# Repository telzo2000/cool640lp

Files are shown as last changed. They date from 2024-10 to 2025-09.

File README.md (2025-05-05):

# cool640lp

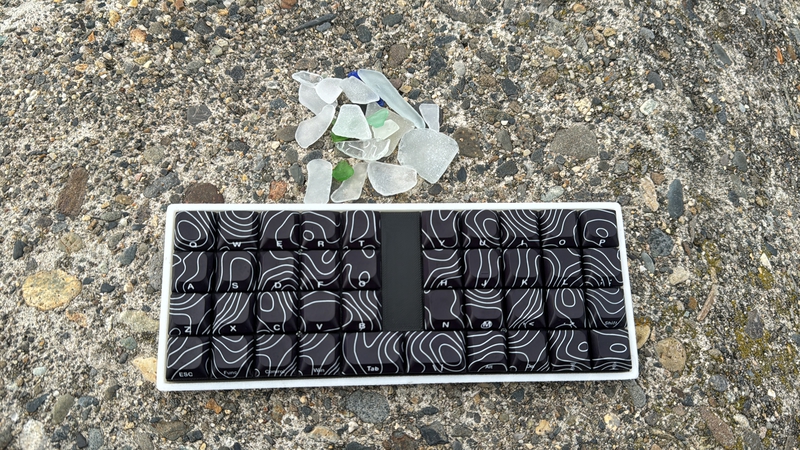
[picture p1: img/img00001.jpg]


## What is cool640lp?

cool640lp is ortholiner keyboard.
<br>
This keyboard has 40 keys.
<br>
This keyboard use Ble Micro Pro,run qmk_firmware.
<br>

## firmware

https://github.com/telzo2000/cool640lp/tree/main/firmware

## build guide

https://github.com/telzo2000/cool640lp/blob/main/buildguide_for_cool640lp.md

<br>

## build log

2024/11/21　build and writen by @MeriNakamura
<br>
https://note.com/merinakamura/n/n6db176bb61fc
<br>
2024/11/26 build and writen by @kazy_developer
<br>
https://note.com/kazy_developer/n/nb938d122a83f?sub_rt=share_sb
<br>
2024/12/26 buile and written by @catfist
<br>
https://note.com/catfist/n/n36a9d9e28e62?sub_rt=share_pb
<br>

### summary

1 Diode soldering
<br>
2 Switch socket soldering
<br>
3  Battery Patrs,etc soldering
<br>
4 Ble Micro Pro and conthrough soldering
<br>
5 Install firmware
<br>
6 Fix the switch plate with screws
<br>
7 Insert the key switch
<br>
8 Fix the bottom case with screws.
<br>
9 Complete
<br>

## Parts list

| No. | Patrs | Quantity | remarks | Suppliers | Cost |
|--|--|--|--|--|--|
|番号|名前|数|備考|調達先|参考価格（送料込）|<br>
|1|PCB|1|40key|[elecrow](https://www.elecrow.com)<br>[JLCPCB](https://jlcpcb.com)<br>[ALLPCB](https://www.allpcb.com)|５枚で20〜30ドル|<br>
|2|BLE Micro Pro|1|MCU Board|[遊舎工房](https://shop.yushakobo.jp/products/ble-micro-pro?variant=37665571340449)|4950円|
|3|Swith socket<br>スイッチソケット|40|choc V2|[遊舎工房](https://yushakobo.jp)<br>[Talp Keyboard](https://talpkeyboard.net)<br>[Daily Craft Keyboard](https://shop.dailycraft.jp)等|10個で165円程度|
|4|Diode<br>ダイオード|40|SMD|[遊舎工房](https://yushakobo.jp)<br>[Talp Keyboard](https://talpkeyboard.net)<br>[Daily Craft Keyboard](https://shop.dailycraft.jp)等|100個で220円程度から|
|5|Switch plate|1|3D Print|||
|6|Bottom case|1|3D Print||
|7|Screw<br>ネジ|8|M2 4mm|DIY shop|10本200円程度|
|8|Spacer<br>スペーサー|4|M2 3mm|DIY shop|10本400円程度|
|9|Conthrou<br>コンスルー|2|3.5mm|[Talp Keyboard](https://talpkeyboard.net)|１個250円程度|
|11|Keyswitch<br>キースイッチ|40|お好みで|[遊舎工房](https://yushakobo.jp)<br>[Talp Keyboard](https://talpkeyboard.net)<br>[Daily Craft Keyboard](https://shop.dailycraft.jp)|１個100程度|
|12|Keycap<br>キーキャップ|40|1Ux38、1.5Ux2|[遊舎工房](https://yushakobo.jp)<br>[Talp Keyboard](https://talpkeyboard.net)<br>[Daily Craft Keyboard](https://shop.dailycraft.jp)||
|13|ボタン電池ホルダー|1|1632|[アリエク](https://ja.aliexpress.com/item/32744211091.html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)<br>|100個で900円ほど|
|14|水平スライドスイッチ|1||[秋月電子](https://akizukidenshi.com/catalog/g/g115370/)|30円|
|15|チップ積層セラミックコンデンサー |1|100μF6.3V F 3216|[秋月電子](https://akizukidenshi.com/catalog/g/g102151/)|10個入り200円|

※13,14,15は[遊舎工房の「Primer29/61用電池部品セット（コイン電池」](https://shop.yushakobo.jp/products/5623)が最適。

In addition, you will need a USB cable, etc.
<br>
この他に、USBケーブル等が必要です。
<br>

## lisence

[CC BY-NC-SA](https://creativecommons.org/licenses/by-nc-sa/4.0/deed.ja)



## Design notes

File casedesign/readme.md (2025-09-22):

# Case design

## switchplate

With my home FDM 3D printer, intersections of less than 0.1mm occur. Therefore, the 3D data is created with a switch frame of 14 mm on each side. With the outsourced stereolithography 3D printer, there are very few intersections of less than 0.1 mm. Therefore, the 3D data is created with a switch frame of 13.85 mm on each side.
<br>
自宅のFDM方式の３Dプリンタでは、0.1mm以下の交差が発生します。そのため、３Dデータは、スイッチの枠を１辺14mmで作成しています。外注先の光造形の３Dプリンタでは、0.1mm以下の交差はあまりないです。そのため、３Dデータは、スイッチの枠を１辺13.85mmで作成しています。
<br>
<br>
The two switches have different claw widths.
<br>
If you use JLCPCB 3D printing survice,
<br>
You shoose
cool640lp_switchplate_for_jlcpcb_rezin.stl
<br>

If the switch you use is Lofree ghost,
<br>
You choose cool640lp_seitchplate_for_lofreeghost.stl.
<br>
If the switch you use is Deep Sea silent mini,
<br>
You choose cool640lp_switchplate_for_ds.stl.
<br>

## bottomcase

Bottomcase has two desigens.
<br>
You can choose whichever bottom case you like and use it.
<br>

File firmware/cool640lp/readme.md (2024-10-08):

# cool640lp

cool640lp

*A short description of the keyboard/project*

* Keyboard Maintainer: [m.ki](https://github.com/telzo2000)
* Hardware Supported: *The PCBs, controllers supported*
* Hardware Availability: *Links to where you can find this hardware*

Make example for this keyboard (after setting up your build environment):

    make cool640lp:default

Flashing example for this keyboard:

    make cool640lp:default:flash

See the [build environment setup](https://docs.qmk.fm/#/getting_started_build_tools) and the [make instructions](https://docs.qmk.fm/#/getting_started_make_guide) for more information. Brand new to QMK? Start with our [Complete Newbs Guide](https://docs.qmk.fm/#/newbs).

## Bootloader

Enter the bootloader in 3 ways:

* **Bootmagic reset**: Hold down the key at (0,0) in the matrix (usually the top left key or Escape) and plug in the keyboard
* **Physical reset button**: Briefly press the button on the back of the PCB - some may have pads you must short instead
* **Keycode in layout**: Press the key mapped to `QK_BOOT` if it is available

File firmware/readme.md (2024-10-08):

# firmware

## Ble Micro Pro

If you read [here](https://sizu.me/m_ki/posts/01s8uea4u7x8) in japanese,you can install Ble Micro Pro on cool640lp.
<br>
日本語で[ここ](https://sizu.me/m_ki/posts/01s8uea4u7x8)を読むと、cool640lpにBle Micro Proをインストールできます。
<br>
<br>

## Pro micro

Install cool640lp_vial.hex to cool640lp using QMK toolbox.
<br>
QMK toolboxを使って、cool640lp_vial.hexをcool640lpにインストールしてください。
<br>

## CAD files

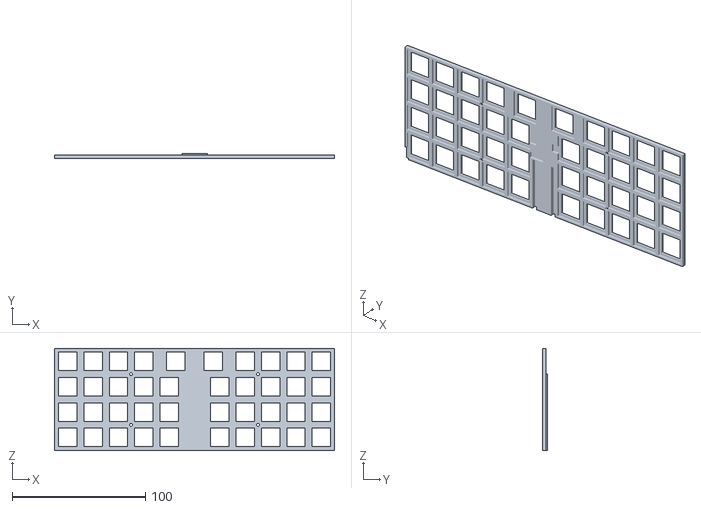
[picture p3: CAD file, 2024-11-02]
casedesign/cool640lp_switchplate_for_jlcpcb_rezin.stl
210.2 x 3.50 x 76.8

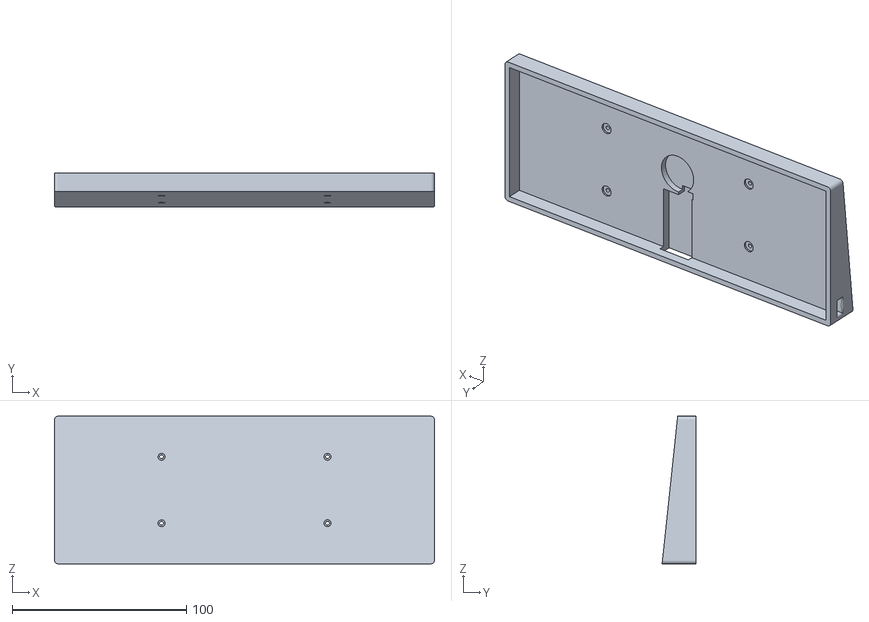
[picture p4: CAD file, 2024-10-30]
casedesign/cool640lp_easybottomcase.stl
218.2 x 19.4 x 84.8

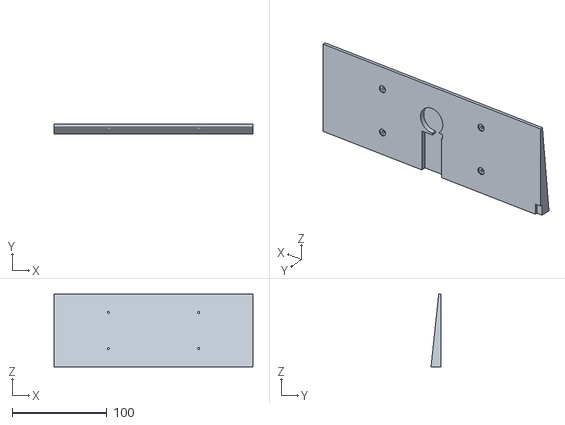
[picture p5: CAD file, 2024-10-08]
casedesign/cool640lp_bottomplate.stl
210.2 x 10.5 x 76.8

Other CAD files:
casedesign/cool640lp_bottomcase.stl
casedesign/cool640lp_switchplate_for_ds v15.stl
casedesign/cool640lp_switchplate_for_lofreeghost.stl

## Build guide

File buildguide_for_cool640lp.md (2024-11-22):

# Build guide

## Build 1

### 1 Diode soldering

Solder the diodes to the back of PCB.
<br>
PCBの裏面にダイオードのハンダ付けをします。
<br>
The diode is compatible with SMD.
<br>
ダイオードは、SMDに対応しています。
<br>
Diodes have polarity, so be careful about the direction in which they are installed.
<br>
ダイオードには極性がありますので、取り付ける向きに注意してください。
<br>

[ダイオード（SMD)のはんだ付けの動画](https://youtu.be/ODk16bd4XkA)

### 2 Switch socket soldering

Solder the switch sockets on the back side.
<br>
裏面にスイッチソケットのハンダ付けをします。
<br>

[８倍速　Switch socketハンダ付け動画](https://youtu.be/E__mHvmIXQo)

### 3 Reset switch soldering

Insert the reset switch from the back of the PCB and solder the exposed part.
<br>
リセットスイッチをPCBの裏面から差し込んで、表面に出た部分をはんだ付けしてください。
<br>

[リセットスイッチのはんだ付けの作業動画](https://youtu.be/Pl24Exfh8b8)

### 4 Battery parts soldering(Bluetooth option)

Solder the slide switch first.
<br>
最初にスライドスッチをはんだ付けします。
<br>

Insert the switch from the back of the PCB with the switch knob facing outward.
<br>
スイッチのつまみが外側に向くようにして、PCBの裏面から差し込みます。

After temporarily fixing it with masking tape, etc., solder the exposed part of the PCB.
<br>
マスキングテープなどで仮固定をしてから、PCBの表面に出た部分をはんだ付けします。
<br>

[スライドスイッチのはんだ付けの作業動画](https://youtu.be/5nkRklibay4)

<br>
Next, solder the capacitor.
<br>
次に、コンデンサをはんだ付けします。
<br>
<br>
First, apply solder to only one side of the two pads.
<br>
最初に、２つあるパッドの片側だけに、はんだを盛り付けます。
<br>
Place the capacitor and fix it by melting the solder.
<br>
コンデンサを置き、もったはんだを溶かしながら、固定します。
<br>
Solder the capacitor, applying solder to the remaining pads.
<br>
残りのパッドにはんだを盛りながら、コンデンサをはんだ付けします。
Finally, attach the battery holder.
<br>

[コンデンサのはんだ付け作業の動画](https://youtu.be/8CFiDMtg21s)

最後に、電池ホルダを取り付けます。
<br>
Insert it from the back side of the PCB and solder the front side. Using masking tape for temporary fixation will make the work easier.
<br>
PCBの裏面から差し込んで、表面をはんだ付けします。仮固定にマスキングテープを使うと作業が簡単になります。
<br>

[電池ホルダのはんだ付けの作業動画](https://youtu.be/ltA8kcLqso4)

### 5a BLE MIcro Pro
Please prepare two con-through (12 pin 3.5mm) instead of the pin header included with BLE Micro Pro.
<br>
ブレマイクロプロ付属のピンヘッダではなく、コンスルー（12ピン 3.5mm）を２つ用意してください。



There is a small hole in the side of the conthru. Insert it into the PCB, being careful to orient the holes the same way.
<br>
コンスルーの側面に小さい穴が開いています。穴を同じ向きになるよう注意して、PCBに差し込んでください。




Insert the BLE Micro Pro into the con-through so that the side with the parts on it faces the PCB. If the BLE Micro Pro easily comes off from the con-through, we recommend soldering. However, due to the structure of the bottom plate of the 3D printer, I think it will be difficult to remove, so no soldering is necessary.
<br>
 BLE Micro Proの部品が載っている方がPCBに面するように、コンスルーに差し込んでください。もし、 BLE Micro Proがコンスルーから外れやすいときははんだ付けをお勧めします。ただし、3Dプリンタのボトムプレートの構造上、外れにくいと思うので、はんだ付け不要です。
<br>
When using a 12-pin con-through, insert it into the 12 holes counting from the USB side of the BLE Micro Pro.
<br>
コンスルー12ピンを使用するとき、BLE Micro ProのUSB側から数えて12箇所分の穴に差し込んでください。
<br>

### 5b Pro Micro
If you are not interested in wireless connectivity, you can keep the price low by using the pro micro.
<br>
もしあなたが無線接続に興味がないのであれば、pro microを使用することで価格を低くすることができます。
<br><br>
Please prepare two con-through (12 pin 3.5mm) instead of the pin header included with pro micro.
<br>
pro micro付属のピンヘッダではなく、コンスルー（12ピン 3.5mm）を２つ用意してください。
<br>

There is a small hole in the side of the conthru. Insert it into the PCB, being careful to orient the holes the same way.
<br>
コンスルーの側面に小さい穴が開いています。穴を同じ向きになるよう注意して、PCBに差し込んでください。

Insert the pro micro into the con-through so that the side with the parts on it faces the PCB. If the pro micro easily comes off from the console, we recommend soldering. However, due to the structure of the bottom plate of the 3D printer, I think it will be difficult to remove, so no soldering is necessary.
<br>
pro microの部品が載っている方がPCBに面するように、コンスルーに差し込んでください。もし、pro microがコンスルーから外れやすいときははんだ付けをお勧めします。ただし、3Dプリンタのボトムプレートの構造上、外れにくいと思うので、はんだ付け不要です。
<br>

Note
<br>
Regarding the PCB of ver.1.0, please correct the part in the image below.
<br>
ver.1.0のPCBについて、次の画像の部分を修正してください。
<br>

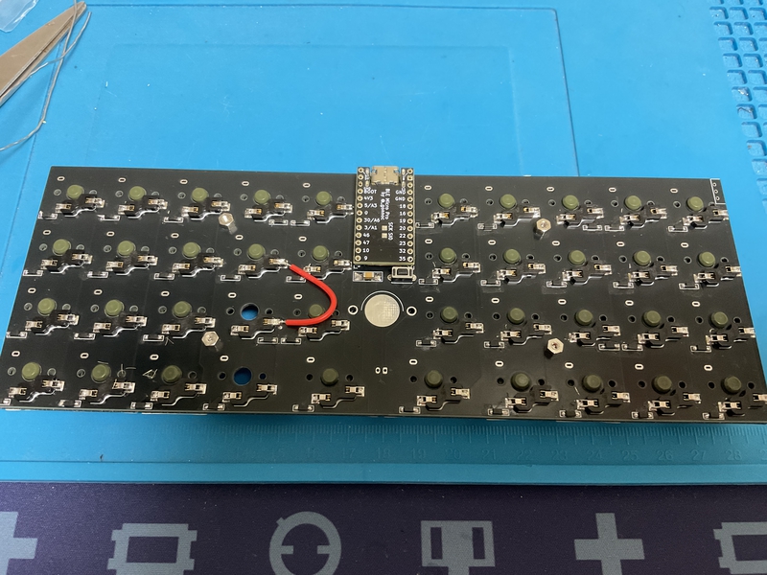
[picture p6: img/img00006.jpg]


### 6a Install firmware （BLE Micro Pro）

Here is an [article](https://sizu.me/m_ki/posts/01s8uea4u7x8) on how to do it.
<br>
ここにやり方の[記事](https://sizu.me/m_ki/posts/01s8uea4u7x8)があります。
<br>

### 6bInstall firmware （pro micro）

There is a hex file [here](https://github.com/telzo2000/cool640lp/tree/main/firmware). Please install it using QMK ToolBox.
<br>

[ここ](https://github.com/telzo2000/cool640lp/tree/main/firmware)にhexファイルがあります。それを、QMK ToolBoxを使って、インストールしてください。

[QMK ToolBox](https://qmk.fm/toolbox)

キーマップ編集サイト
[Vial](https://get.vial.today/)

### 7 Fix the switch plate 

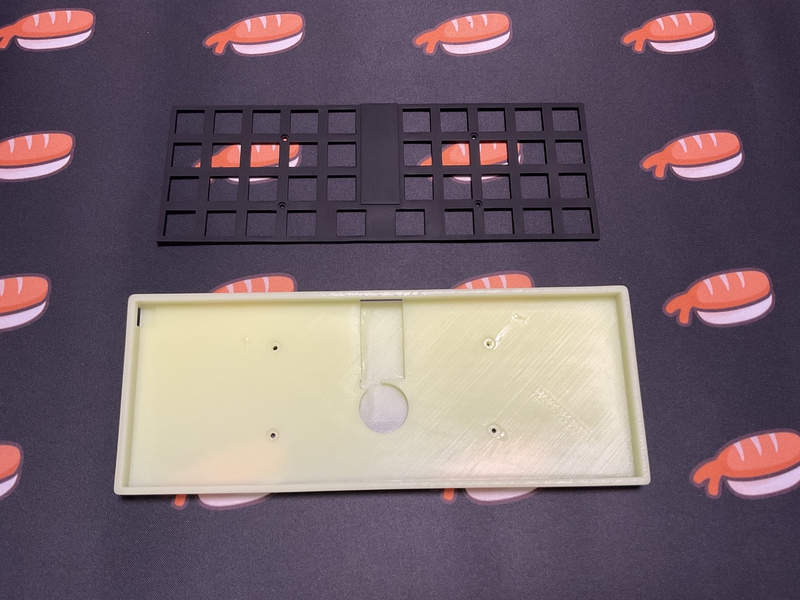
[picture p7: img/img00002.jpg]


Insert the M2 screws (4mm) into the 3D printed switch plate and the PCB in that order, and secure them with M2 spacers (3mm) from the bottom of the PCB.
<br>
3Dプリントのスイッチプレート、PCBの順でM2ネジ（4mm）の順で差し込み、PCB下面からM2スペーサー3mm）で固定します。

<br><br>

### 8 Insert the key switch

Insert the key switch from the switch plate side.
<br>
スイッチプレート側からキースイッチを差し込んでいきます。
<br>

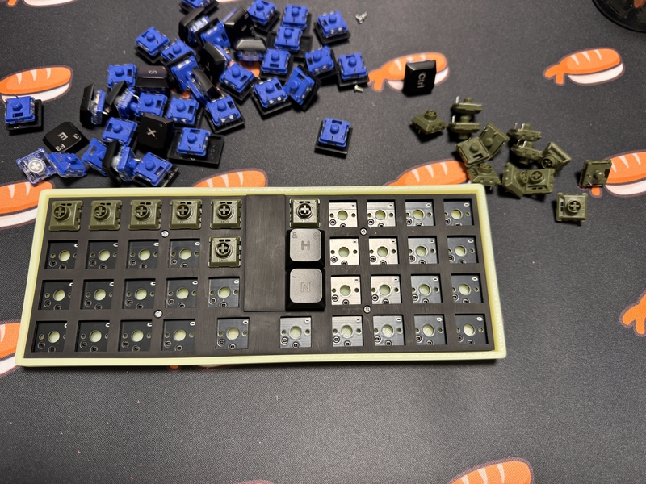
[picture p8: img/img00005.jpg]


<br>

### 9 Fix the bottom case with screws

Secure the spacer fixed to the bottom plate and PCB with four M2 screws (4mm).
<br>
ボトムプレートとPCBに固定したスペーサーをM2ネジ（4mm）４本で固定します。

### 11 Complete

Attach your favorite keycaps and you're done.
<br>
お気に入りのキーキャップをつけて完成です。
<br>
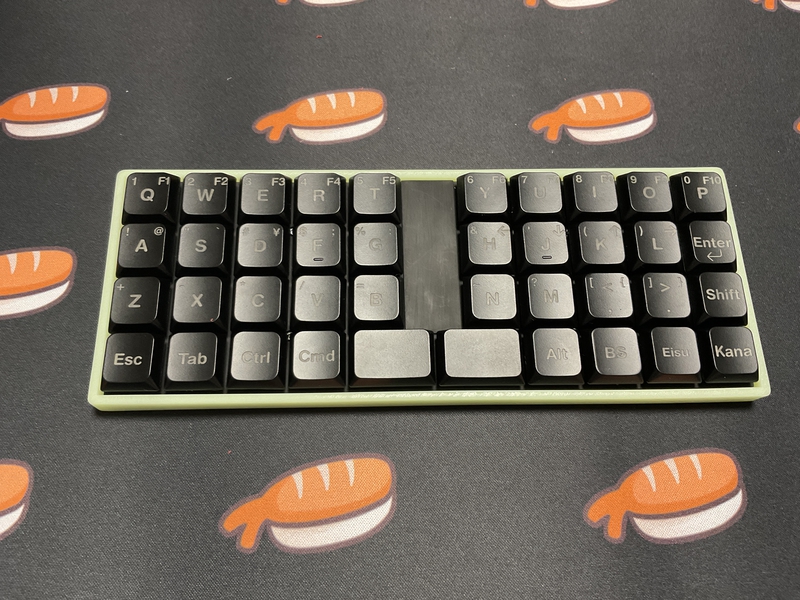
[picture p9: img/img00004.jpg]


<br>
Welcome to the world of the best keyboards.
<br>
最高のキーボードの世界にようこそ。
<br>

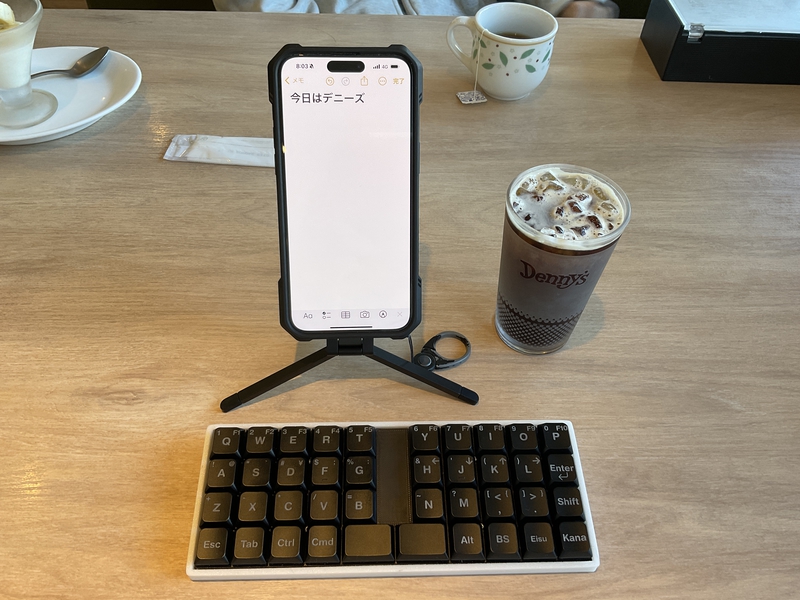
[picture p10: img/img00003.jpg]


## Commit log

2024-11-12 buildguide_for_cool640lp.md を更新
2024-11-26 README.md を更新
